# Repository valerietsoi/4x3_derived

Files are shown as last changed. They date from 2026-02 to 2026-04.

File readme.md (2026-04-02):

# 4x3 derived

## description 
4x3, four columns and three rows.

Derived, as in derived from the [previous 2x2 macropad](https://github.com/valerietsoi/2squared).

PCB and firmware tested.

Stabless only.

<br>

## pics
| | |
| --- | --- |
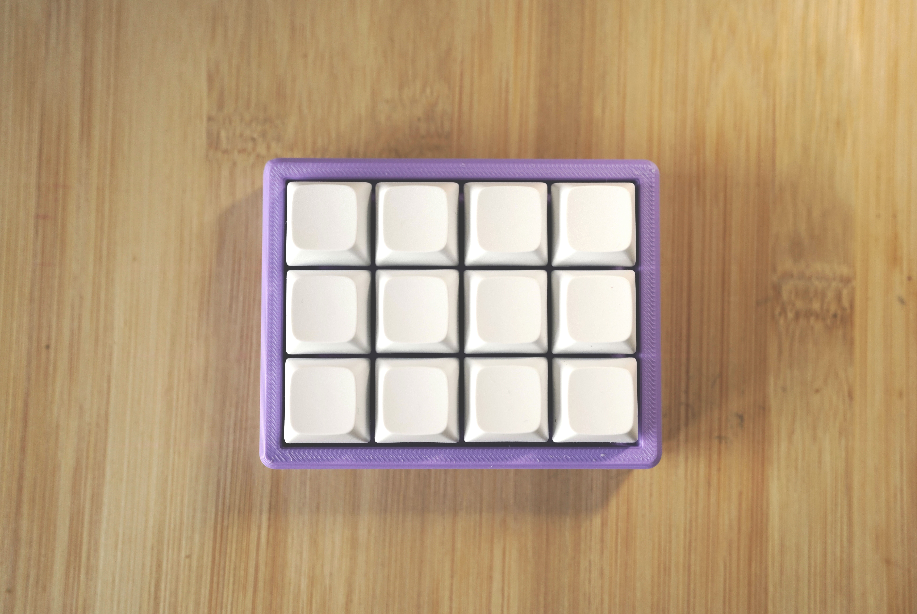
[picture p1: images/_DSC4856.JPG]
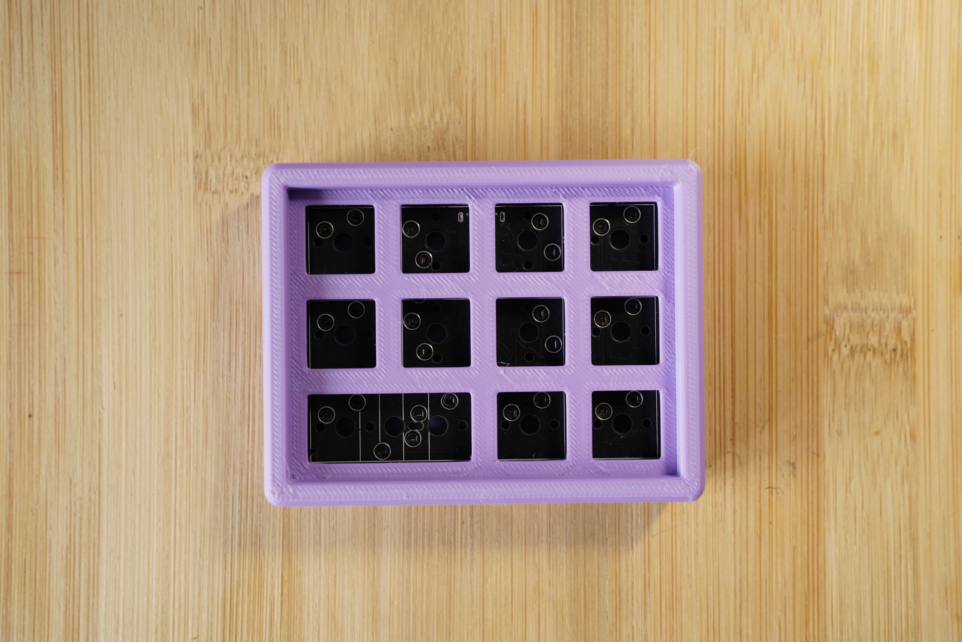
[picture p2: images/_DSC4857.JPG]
|  | |
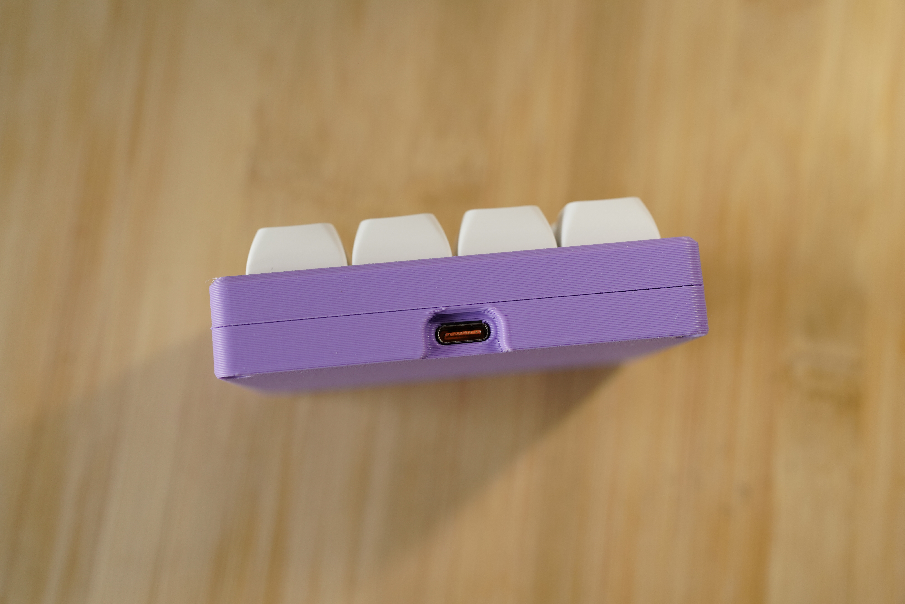
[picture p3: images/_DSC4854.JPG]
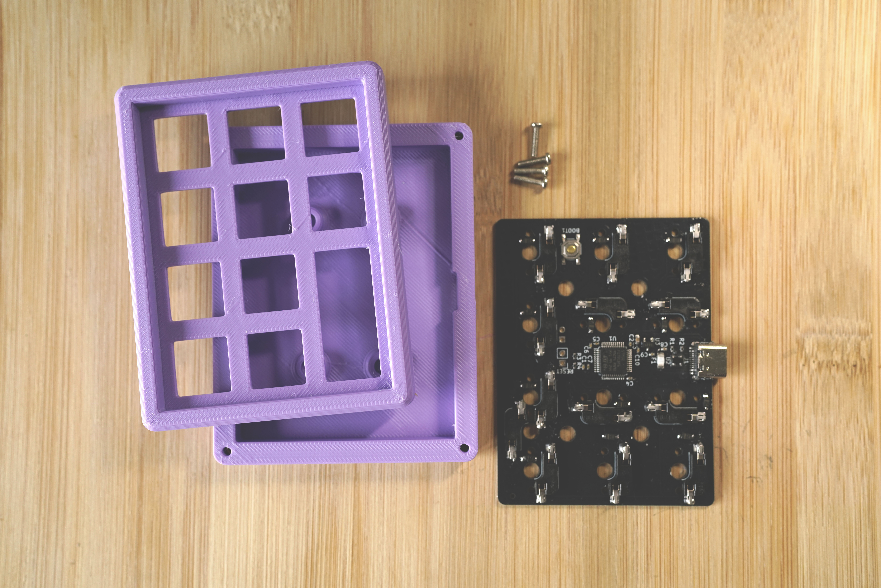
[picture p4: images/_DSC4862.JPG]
|  |  |
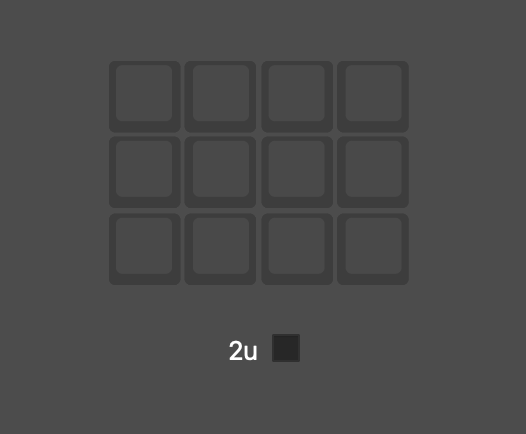
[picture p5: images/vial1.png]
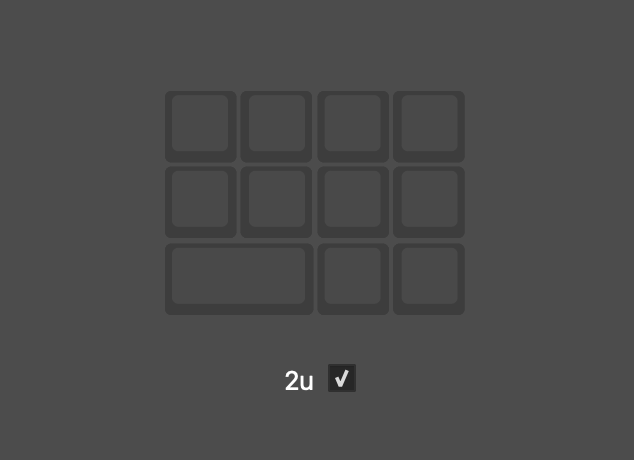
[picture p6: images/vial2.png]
|  |  |
<br>

## firmware

Use [QMK toolbox](https://qmk.fm/toolbox) to flash the pre-compiled `.bin`. Source files to be uploaded.

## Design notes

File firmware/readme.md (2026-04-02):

# vt_projects/3x3handwired

vt_projects/3x3handwired

*A short description of the keyboard/project*

* Keyboard Maintainer: [Valerie Tsoi](https://github.com/valerietsoi)
* Hardware Supported: *The PCBs, controllers supported*
* Hardware Availability: *Links to where you can find this hardware*

Make example for this keyboard (after setting up your build environment):

    make vt_projects/3x3handwired:default

Flashing example for this keyboard:

    make vt_projects/3x3handwired:default:flash

See the [build environment setup](https://docs.qmk.fm/#/getting_started_build_tools) and the [make instructions](https://docs.qmk.fm/#/getting_started_make_guide) for more information. Brand new to QMK? Start with our [Complete Newbs Guide](https://docs.qmk.fm/#/newbs).

## Bootloader

Enter the bootloader in 3 ways:

* **Bootmagic reset**: Hold down the key at (0,0) in the matrix (usually the top left key or Escape) and plug in the keyboard
* **Physical reset button**: Briefly press the button on the back of the PCB - some may have pads you must short instead
* **Keycode in layout**: Press the key mapped to `QK_BOOT` if it is available

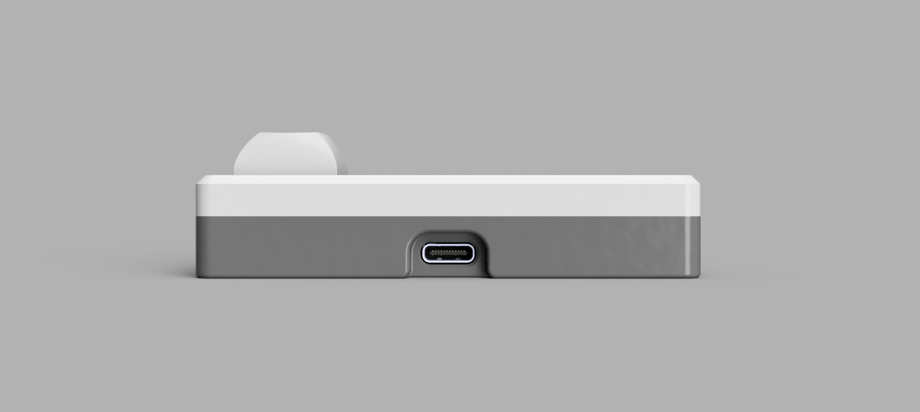
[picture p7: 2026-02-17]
images/render2.png

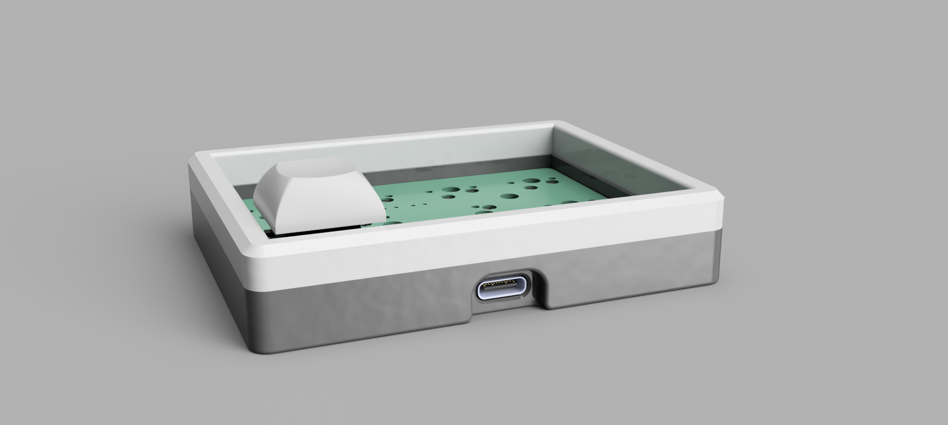
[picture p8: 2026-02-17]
images/render4.png

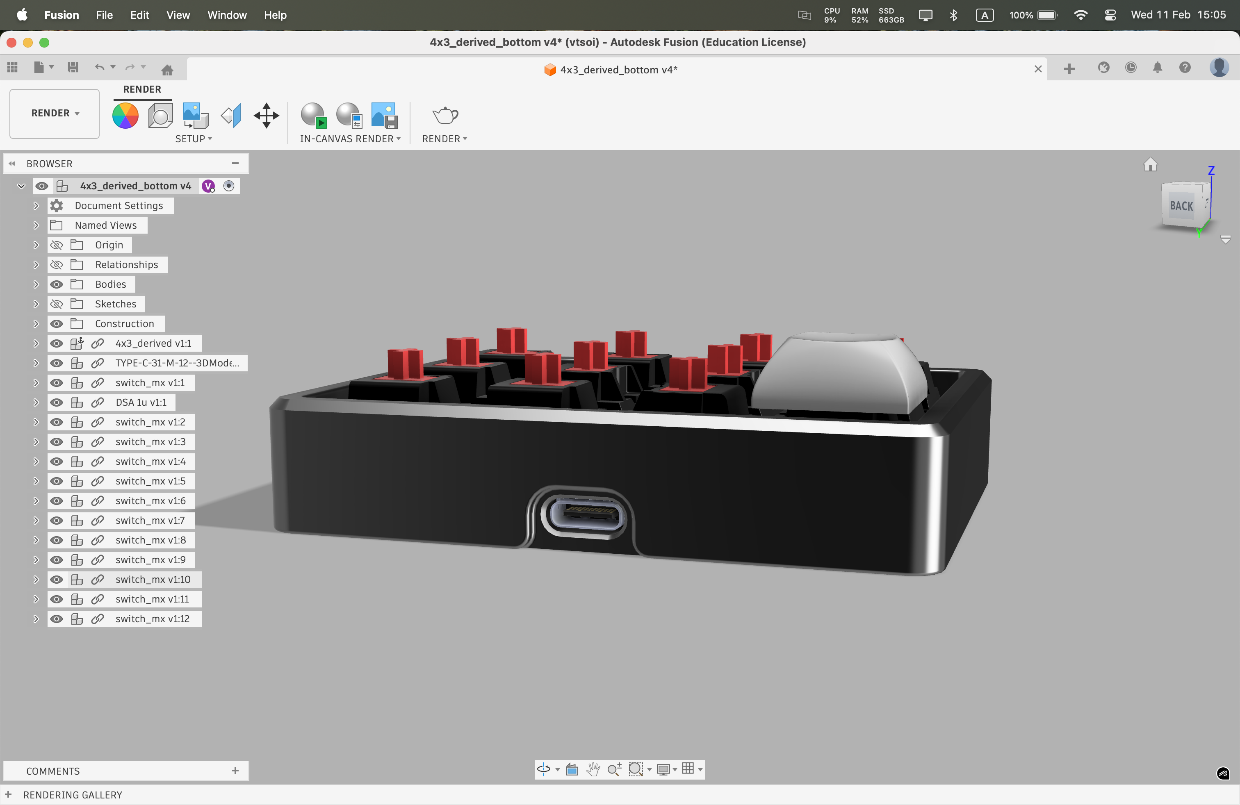
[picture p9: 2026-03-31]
renders/Screenshot 2026-02-11 at 15.05.02.png

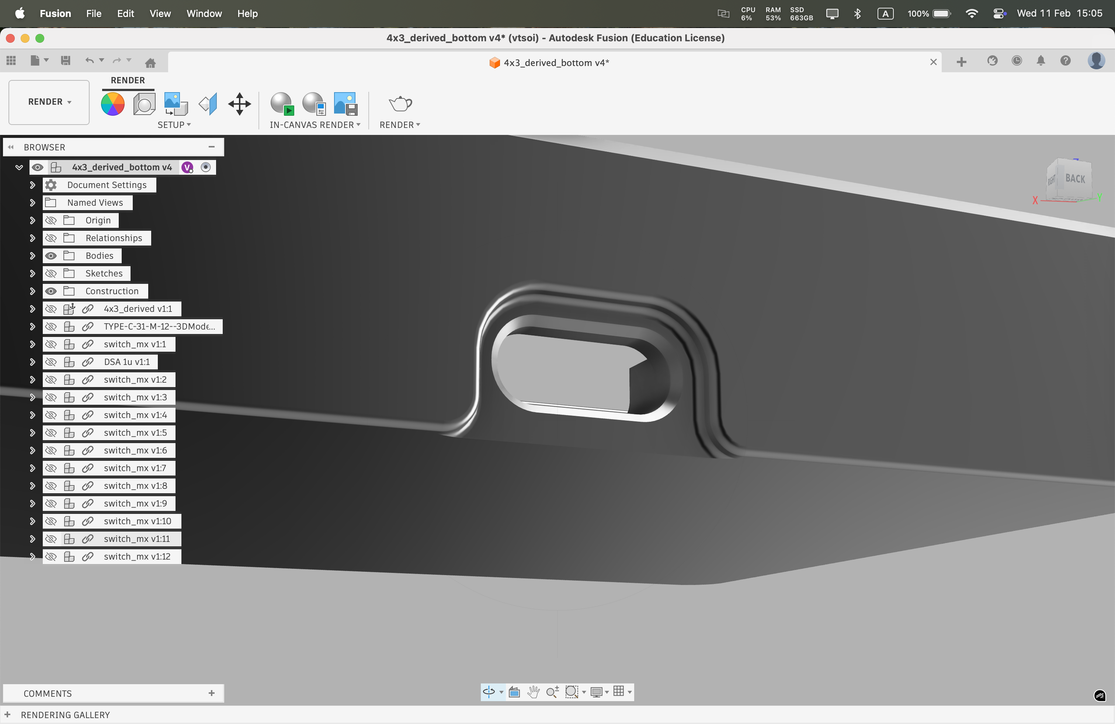
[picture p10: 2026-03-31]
renders/Screenshot 2026-02-11 at 15.05.41.png

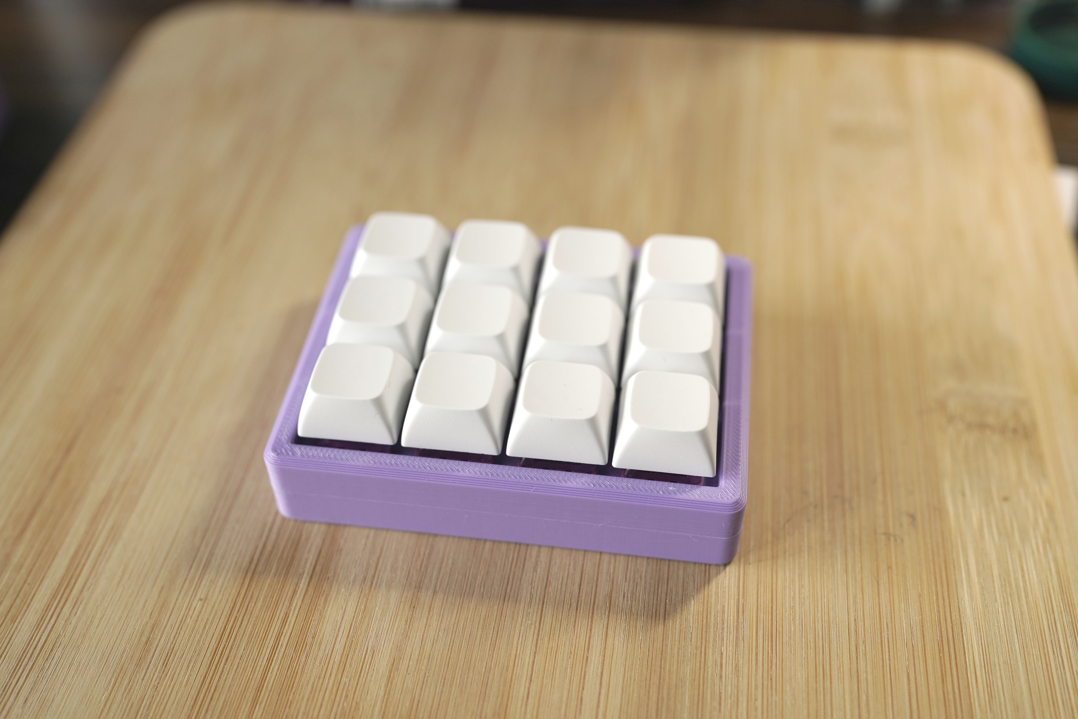
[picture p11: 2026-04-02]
images/_DSC4848.JPG

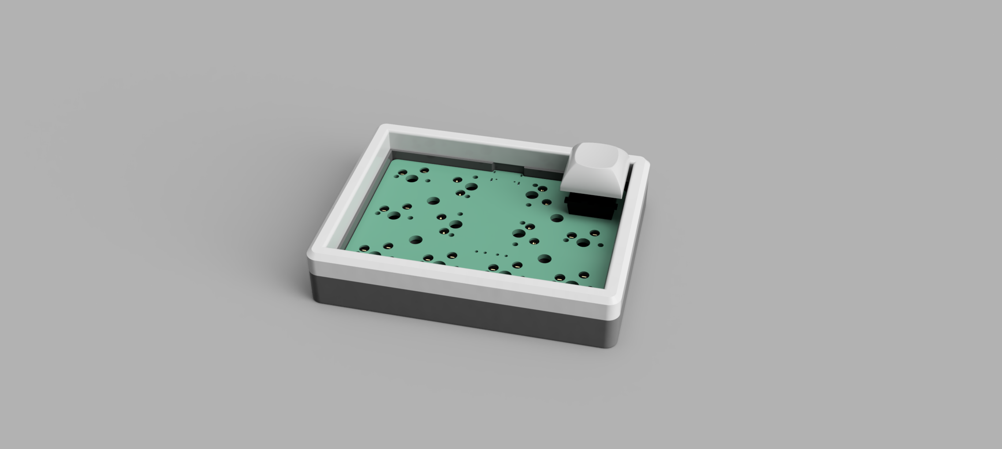
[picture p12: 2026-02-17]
images/render3.png

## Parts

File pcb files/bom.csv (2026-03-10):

Designator | Footprint | Quantity | Value | LCSC Part #
BOOT1 | SW_SPST_TL3342 | 1 | SW_SPST | C318884
C1, C10, C3, C5, C6, C8, C9 | 0402 | 7 | 100nF | C1525
C2 | 0603 | 1 | 10uF | C19702
C4, C7 | 0402 | 2 | 1uF | C52923
D1, D10, D11, D12, D2, D3, D4, D5, D6, D7, D8, D9 | Diode_SOD-123 | 12 | Diode | C81598
F1 | 1206 | 1 | 500mA | C369160
J1 | USB_C_Receptacle_HRO_TYPE-C-31-M-12 | 1 | USB_C_Receptacle_USB2.0
J6, RESET | PinHeader_1x02_P2.54mm_Vertical | 2 | Conn_01x02_Socket
R1, R2, R3, R4 | 0402 | 4 | 5.1k | C25905
S1, S10, S11, S12, S2, S3, S4, S5, S6, S7, S8, S9 | Hotswap_MX_Plated_1.00u | 12 | Keyswitch
U1 | LQFP-48_7x7mm_P0.5mm | 1 | STM32F072CBT6 | C81720
U2 | SOT-143 | 1 | PRTR5V0U2X | C2827688
U3 | SOT-23 | 1 | XC6206PxxxMR-Regulator_Linear | C5446

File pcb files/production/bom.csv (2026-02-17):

Designator | Footprint | Quantity | Value | LCSC Part #
BOOT1 | SW_SPST_TL3342 | 1 | SW_SPST
C1, C10, C3, C5, C6, C8, C9 | 0402 | 7 | 100nF | C307331
C2 | 0603 | 1 | 10uF | C307331
C4, C7 | 0402 | 2 | 1uF | C307331
D1, D10, D11, D12, D2, D3, D4, D5, D6, D7, D8, D9 | Diode_SOD-123 | 12 | Diode
F1 | 1206 | 1 | 500mA | C135341
J1 | USB_C_Receptacle_HRO_TYPE-C-31-M-12 | 1 | USB_C_Receptacle_USB2.0
J6, RESET | PinHeader_1x02_P2.54mm_Vertical | 2 | Conn_01x02_Socket
R1, R2, R3, R4 | 0402 | 4 | 5.1k
S1, S10, S11, S12, S2, S3, S4, S5, S6, S7, S8, S9 | Hotswap_MX_Plated_1.00u | 12 | Keyswitch
U1 | LQFP-48_7x7mm_P0.5mm | 1 | STM32F072CBT6
U2 | SOT-143 | 1 | PRTR5V0U2X | C2827688
U3 | SOT-23 | 1 | XC6206PxxxMR-Regulator_Linear | C5446

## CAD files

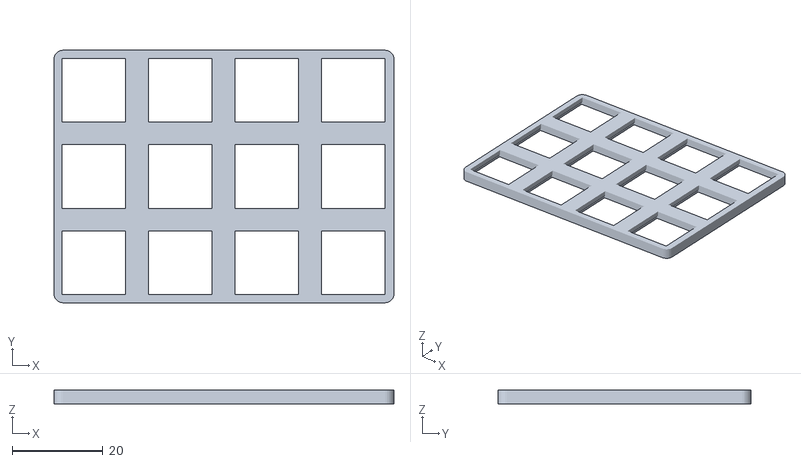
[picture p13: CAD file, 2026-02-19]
case files/4x3_derived_plate.stl
75.0 x 55.7 x 3.00

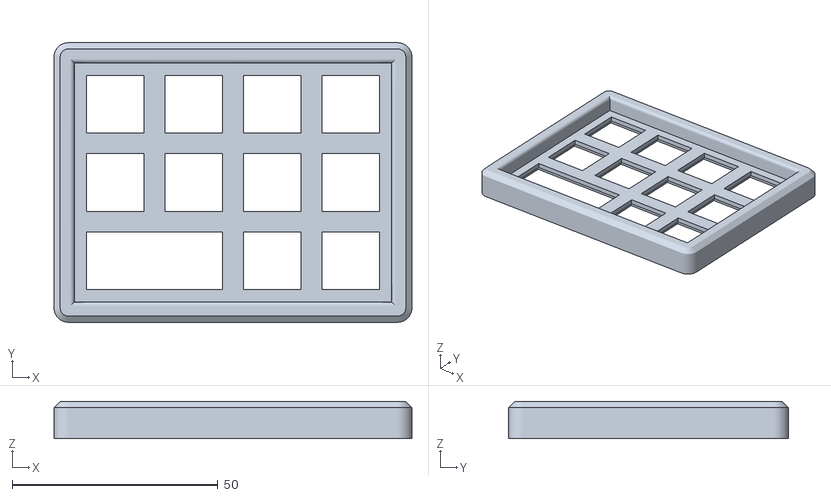
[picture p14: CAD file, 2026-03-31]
case files/integrated plate/4x3_derived_intplate_top_supports2u.stl
87.0 x 68.0 x 9.00

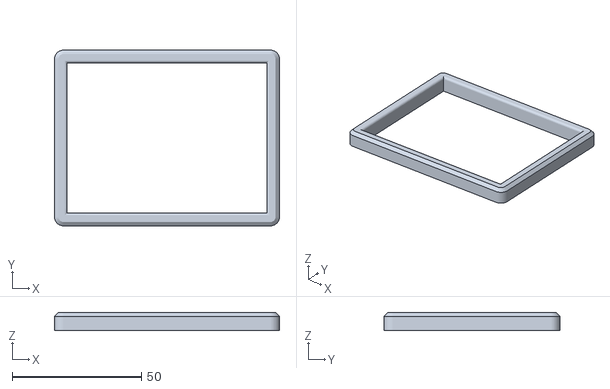
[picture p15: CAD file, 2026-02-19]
case files/4x3_derived_top.stl
87.0 x 68.0 x 7.00

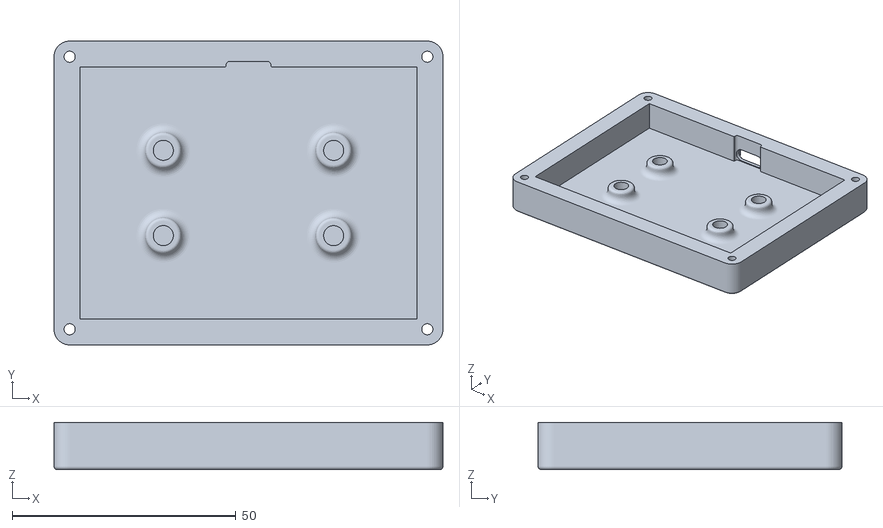
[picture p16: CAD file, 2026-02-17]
case files/4x3_derived_bottom.stl
87.0 x 68.0 x 10.6

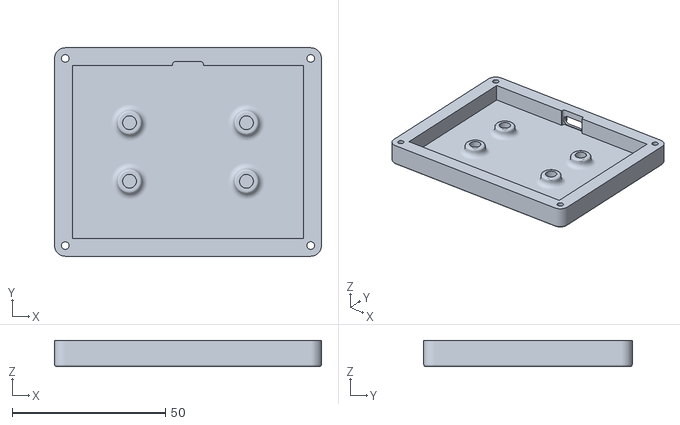
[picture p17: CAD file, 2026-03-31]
case files/integrated plate/4x3_derived_intplate_bot.stl
87.0 x 68.0 x 8.60

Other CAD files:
case files/integrated plate/4x3_derived_intplate_top.stl

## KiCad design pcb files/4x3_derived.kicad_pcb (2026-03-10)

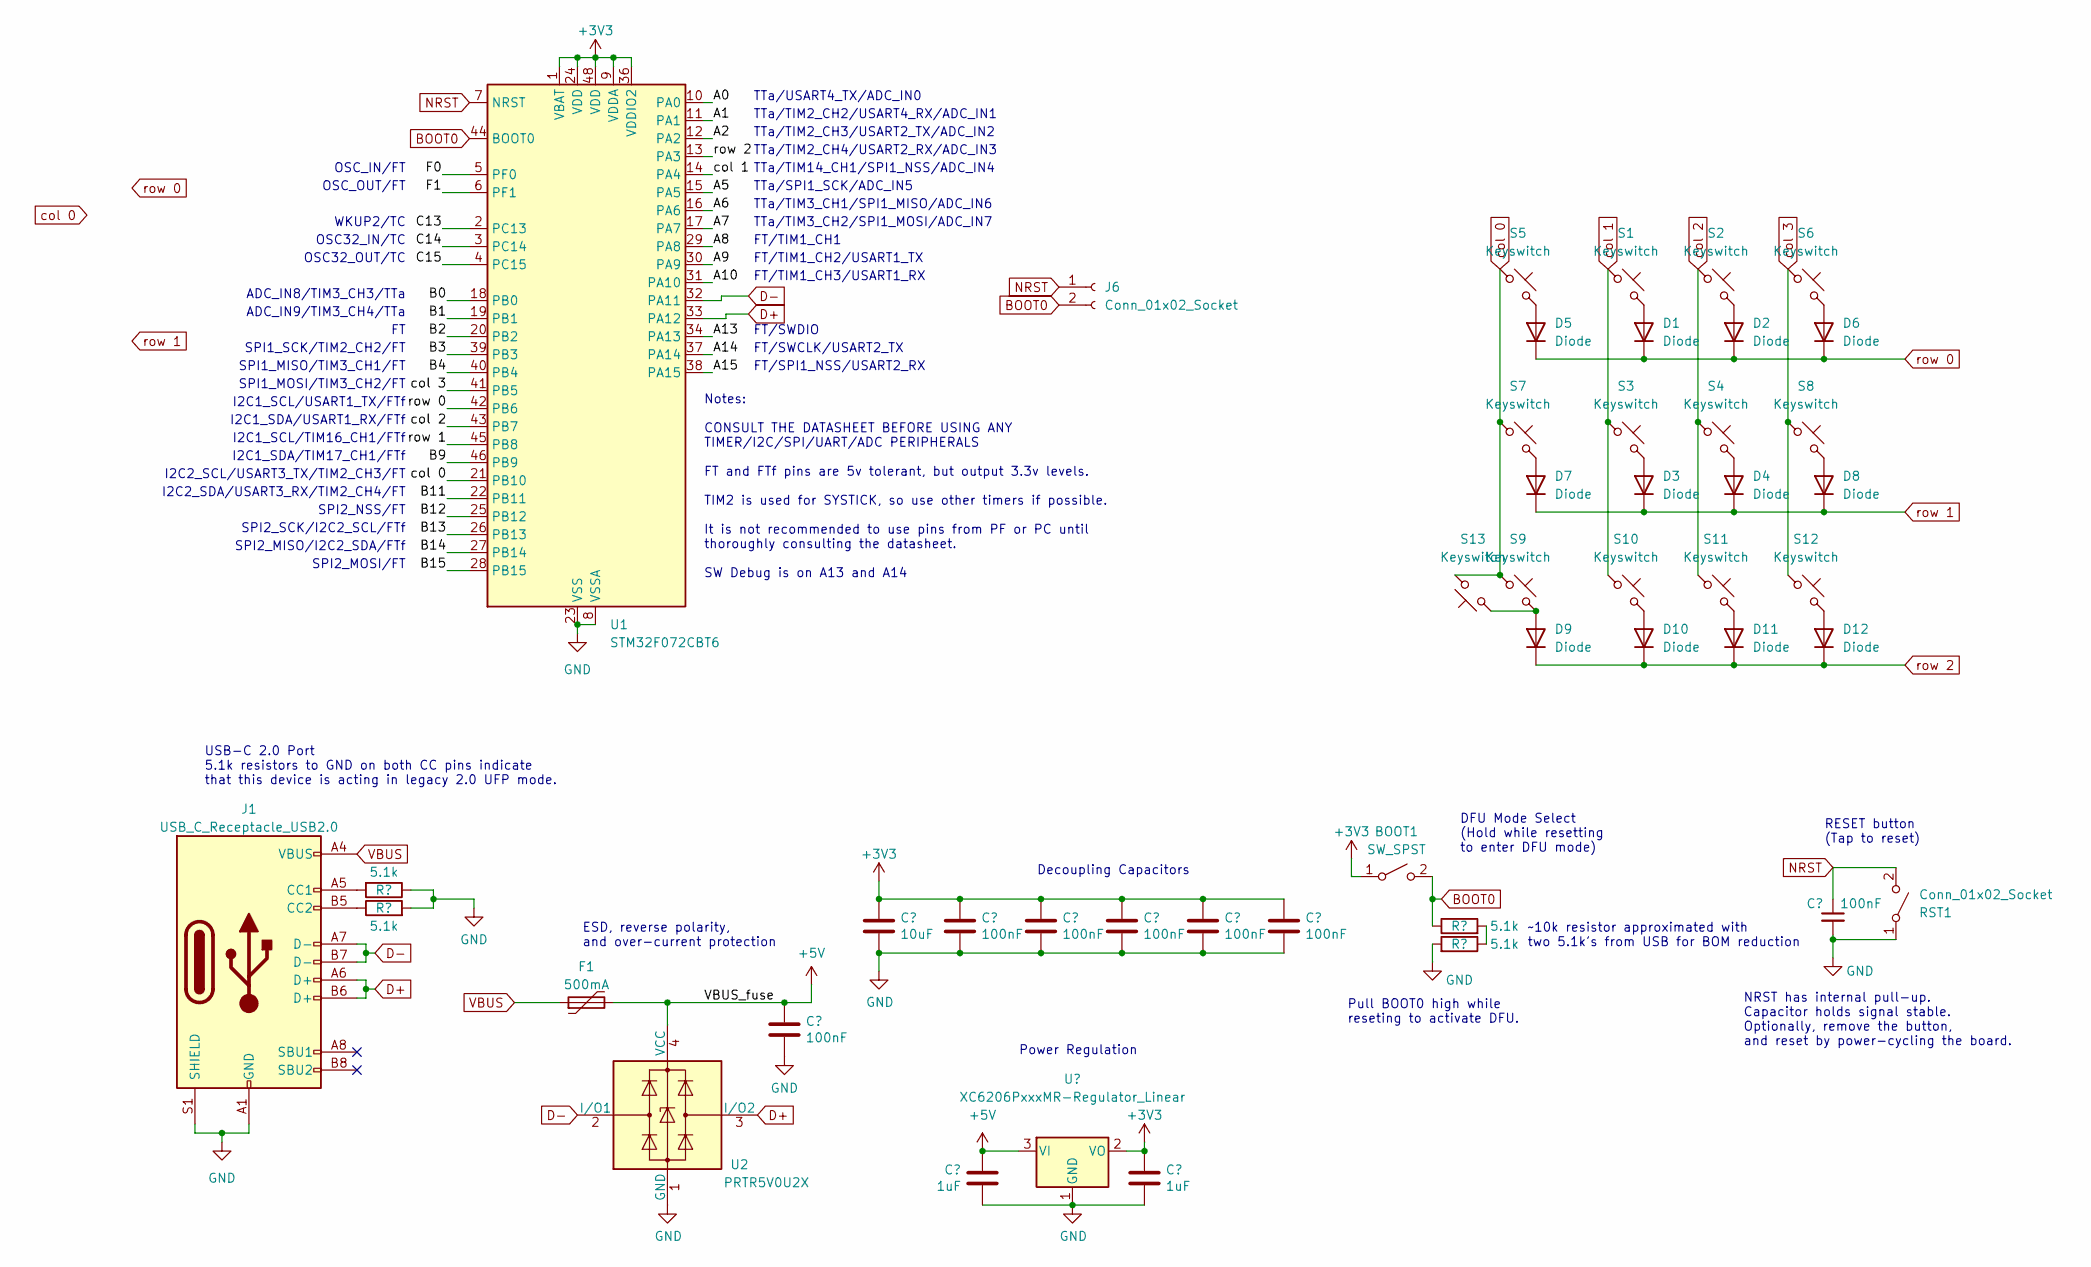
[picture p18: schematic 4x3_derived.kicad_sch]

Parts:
BOOT1: SW_SPST; SW_SPST_TL3342
C1, C3, C4, C5, C6, C7, C8: 100nF; C_0402_1005Metric; LCSC C307331
C2: 10uF; C_0603_1608Metric; LCSC C307331
C9, C10: 1uF; C_0402_1005Metric; LCSC C307331
D1, D2, D3, D4, D5, D6, D7, D8, D9, D10, D11, D12: Diode; Diode_SOD-123
F1: 500mA; Fuse_1206_3216Metric; LCSC C135341
J1: USB_C_Receptacle_USB2.0; USB_C_Receptacle_HRO_TYPE-C-31-M-12; JlcRotOffset 180
J6: Conn_01x02_Socket; PinHeader_1x02_P2.54mm_Vertical
R1, R2, R3, R4: 5.1k; R_0402_1005Metric
RST1: Conn_01x02_Socket; PinHeader_1x02_P2.54mm_Vertical
S1, S2, S3, S4, S5, S6, S7, S8, S9, S10, S11, S12, S13: Keyswitch; Hotswap_MX_Plated_1.00u
U1: STM32F072CBT6; LQFP-48_7x7mm_P0.5mm; JlcRotOffset 90
U2: PRTR5V0U2X; SOT-143; LCSC C2827688
U3: XC6206PxxxMR-Regulator_Linear; SOT-23; LCSC C5446

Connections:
/A0: U1.10 (PA0)
/A1: U1.11 (PA1)
/A2: U1.12 (PA2)
/A5: U1.15 (PA5)
/A6: U1.16 (PA6)
/A7: U1.17 (PA7)
/A8: U1.29 (PA8)
/A9: U1.30 (PA9)
/A10: U1.31 (PA10)
/A13: U1.34 (PA13)
/A14: U1.37 (PA14)
/A15: U1.38 (PA15)
/B0: U1.18 (PB0)
/B1: U1.19 (PB1)
/B2: U1.20 (PB2)
/B3: U1.39 (PB3)
/B4: U1.40 (PB4)
/B9: U1.46 (PB9)
/B11: U1.22 (PB11)
/B12: U1.25 (PB12)
/B13: U1.26 (PB13)
/B14: U1.27 (PB14)
/B15: U1.28 (PB15)
/C13: U1.2 (PC13)
/C14: U1.3 (PC14)
/C15: U1.4 (PC15)
/F0: U1.5 (PF0)
/F1: U1.6 (PF1)
BOOT0: BOOT1.2 (B), J6.2, R3.1, U1.44 (BOOT0)
D+: J1.A6 (D+), J1.B6 (D+), U1.33 (PA12), U2.3 (I/O2)
D-: J1.A7 (D-), J1.B7 (D-), U1.32 (PA11), U2.2 (I/O1)
GND: C1.2, C2.2, C3.2, C4.2, C5.2, C6.2, C7.2, C8.2, C9.2, C10.2, J1.A1 (GND), J1.A12 (GND), J1.B1 (GND), J1.B12 (GND), J1.S1 (SHIELD), R1.1, R2.2, R4.2, U1.8 (VSSA), U1.23 (VSS), U1.35 (VSS), U1.47 (VSS), U2.1 (GND), U3.1 (GND); also elsewhere on the board
unnamed: D1.2 (A), S1.2
unnamed: D2.2 (A), S2.2
unnamed: D3.2 (A), S3.2
unnamed: D4.2 (A), S4.2
unnamed: D5.2 (A), S5.2
unnamed: D6.2 (A), S6.2
unnamed: D7.2 (A), S7.2
unnamed: D8.2 (A), S8.2
unnamed: D9.2 (A), S9.2, S13.1
unnamed: D10.2 (A), S10.2
unnamed: D11.2 (A), S11.2
unnamed: D12.2 (A), S12.2
unnamed: J1.A5 (CC1), R1.2
unnamed: J1.B5 (CC2), R2.1
unnamed: R3.2, R4.1
VBUS: F1.1, J1.A4 (VBUS), J1.A9 (VBUS), J1.B4 (VBUS), J1.B9 (VBUS)
col 0: S5.1, S7.1, S9.1, S13.2, U1.21 (PB10)
col 1: S1.1, S3.1, S10.1, U1.14 (PA4)
col 2: S2.1, S4.1, S11.1, U1.43 (PB7)
col 3: S6.1, S8.1, S12.1, U1.41 (PB5)
row 0: D1.1 (K), D2.1 (K), D5.1 (K), D6.1 (K), U1.42 (PB6)
row 1: D3.1 (K), D4.1 (K), D7.1 (K), D8.1 (K), U1.45 (PB8)
row 2: D9.1 (K), D10.1 (K), D11.1 (K), D12.1 (K), U1.13 (PA3)

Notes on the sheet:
RESET button (Tap to reset)
FT/TIM1_CH2/USART1_TX
Decoupling Capacitors
SPI2_SCK/I2C2_SCL/FTf
OSC_IN/FT
TTa/TIM2_CH2/USART4_RX/ADC_IN1
I2C2_SCL/USART3_TX/TIM2_CH3/FT
DFU Mode Select (Hold while resetting to enter DFU mode)
TTa/SPI1_SCK/ADC_IN5
SPI1_MOSI/TIM3_CH2/FT
TTa/USART4_TX/ADC_IN0
SPI2_NSS/FT
I2C1_SCL/TIM16_CH1/FTf
I2C1_SCL/USART1_TX/FTf
TTa/TIM14_CH1/SPI1_NSS/ADC_IN4
SPI1_MISO/TIM3_CH1/FT
ADC_IN9/TIM3_CH4/TTa
TTa/TIM3_CH1/SPI1_MISO/ADC_IN6
USB-C 2.0 Port 5.1k resistors to GND on both CC pins indicate that this device is acting in legacy 2.0 UFP mode.
I2C2_SDA/USART3_RX/TIM2_CH4/FT
SPI2_MISO/I2C2_SDA/FTf
TTa/TIM2_CH3/USART2_TX/ADC_IN2
Power Regulation
OSC_OUT/FT
ESD, reverse polarity, and over-current protection
I2C1_SDA/TIM17_CH1/FTf
OSC32_OUT/TC
FT/SWCLK/USART2_TX
OSC32_IN/TC
FT/SPI1_NSS/USART2_RX
TTa/TIM2_CH4/USART2_RX/ADC_IN3
FT/TIM1_CH3/USART1_RX
NRST has internal pull-up. Capacitor holds signal stable. Optionally, remove the button, and reset by power-cycling the board.
~10k resistor approximated with two 5.1k's from USB for BOM reduction
I2C1_SDA/USART1_RX/FTf
FT/TIM1_CH1
Notes: CONSULT THE DATASHEET BEFORE USING ANY TIMER/I2C/SPI/UART/ADC PERIPHERALS FT and FTf pins are 5v tolerant, but output 3.3v levels. TIM2 is used for SYSTICK, so use other timers if possible. It is not recommended to use pins from PF or PC until thoroughly consulting the datasheet. SW Debug is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
WKUP2/TC
Pull BOOT0 high while reseting to activate DFU.
TTa/TIM3_CH2/SPI1_MOSI/ADC_IN7

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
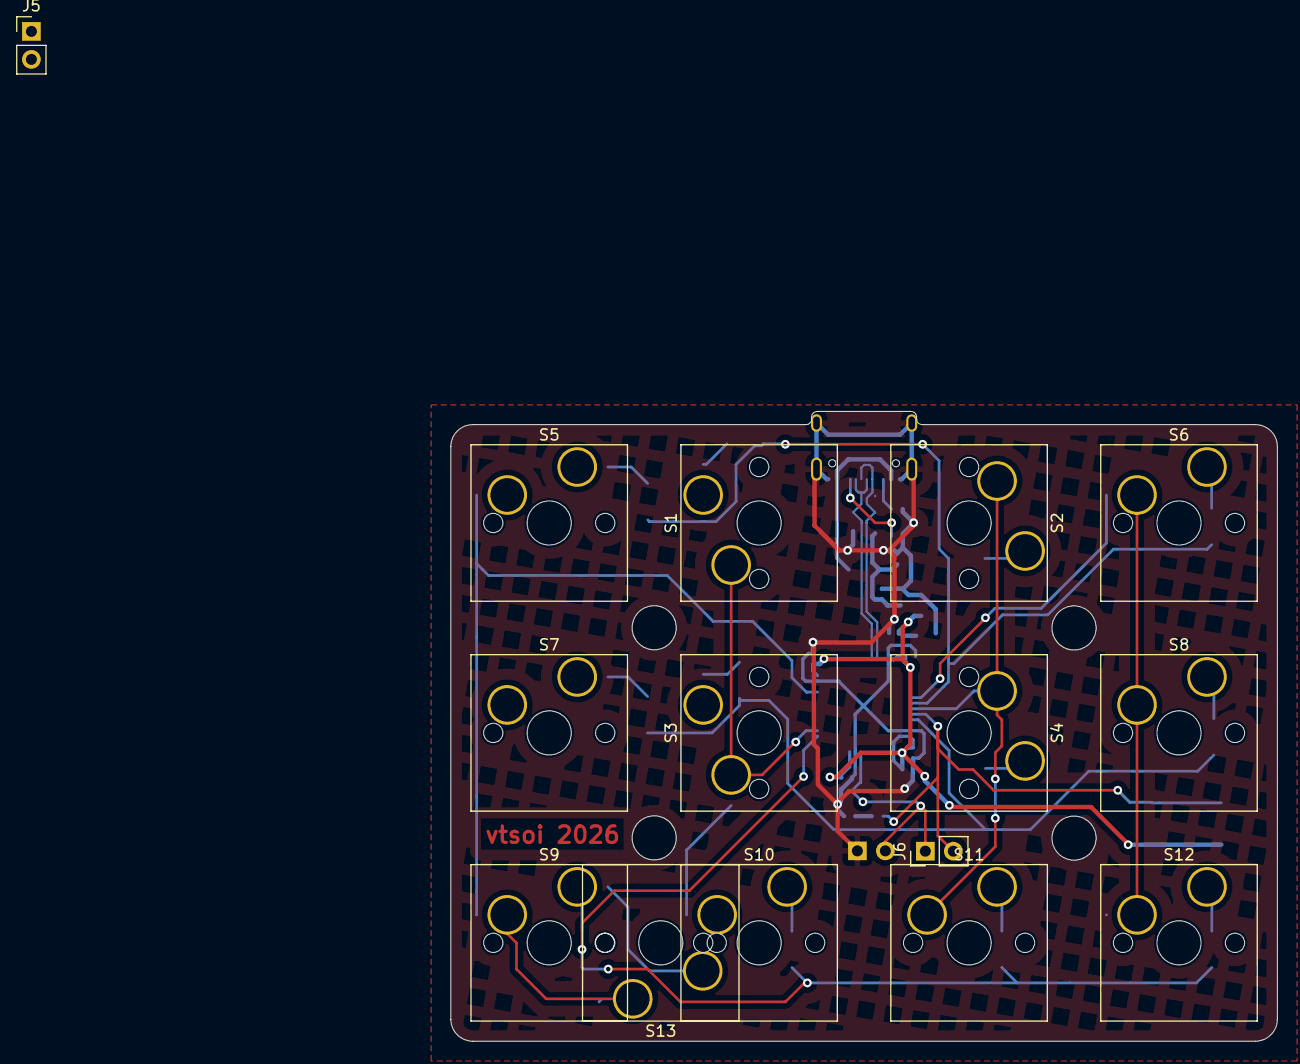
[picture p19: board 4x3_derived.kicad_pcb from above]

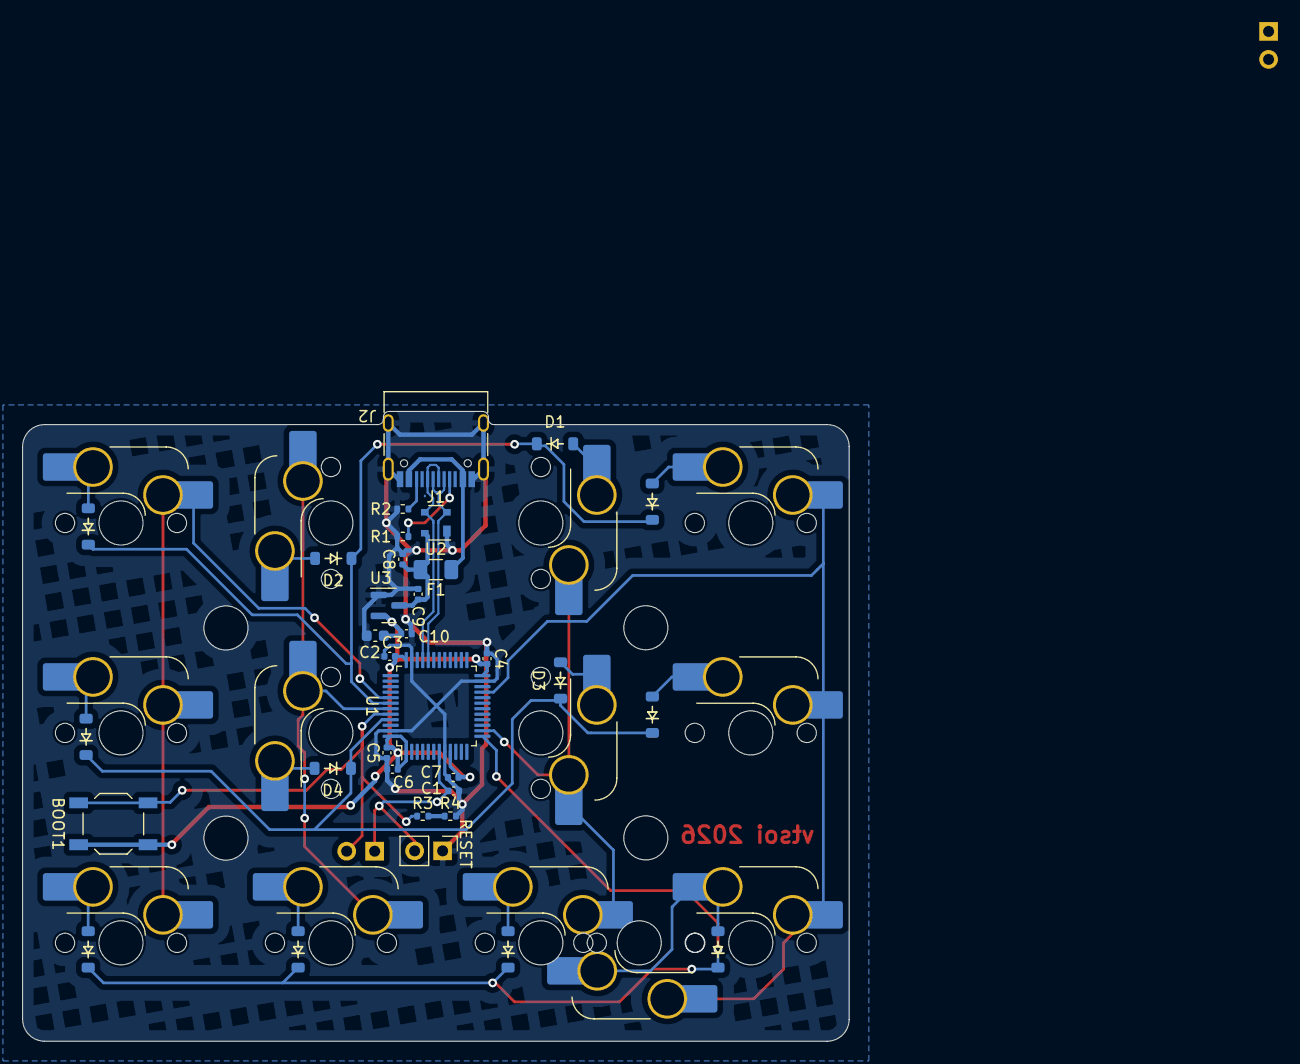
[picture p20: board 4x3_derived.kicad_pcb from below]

Board: 2 copper layers, 75.0 x 57.2 mm, 48 parts (33 on the bottom side), 30 nets.

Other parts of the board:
J5: Conn_01x02_Socket; PinHeader_1x02_P2.54mm_Vertical
RESET: Conn_01x02_Socket; PinHeader_1x02_P2.54mm_Vertical

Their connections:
GND: J5.1 (A), RESET.1 (A); also elsewhere on the board

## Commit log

2026-02-17 files added
    [4x3_derived.kicad_pcb, 4x3_derived.kicad_sch, 4x3_derived_bottom.stl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]
2026-02-19 case files
    [4x3_derived_plate.stl, 4x3_derived_top.stl]
2026-03-10 pcb updated
    [4x3_derived.kicad_pcb, 4x3_derived.kicad_sch, bom.csv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]
2026-03-31 2u compatible integrated plate top case
    [4x3_derived_bottom.stl, 4x3_derived_intplate_bot.stl, 4x3_derived_intplate_top.stl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]
